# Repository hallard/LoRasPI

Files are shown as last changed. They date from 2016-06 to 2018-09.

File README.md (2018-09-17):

Raspberry PI Lora Gateway/Node for RFM92/95/96/98/69HCW Modules
===============================================================

This shield is used to hold HopeRF [Lora module][4] Software with Raspbery PI. it has just few minimal features and it's working for [TTN network][1]. 

I tweaked the [Single LoraWan Gateway][5] to get it working out of the box. It should also works with [HAB Supplies Lora Gateway][7] (same pinout), see this excellent [Dave's article][6].

This shield can also act as a LoraWAN Node/gateway using this custom dedicated software    
- RPI version of [LMIC][9] stack. This LMIC is working with this shield, see [readme][13] of repo.
- for RF69 networks using the excellent [RadioHead][10] customized library. This version is working with this shield, see [readme][12] of library.

As you can see, this shield is small but can do a lot but if you need a shield with more features (modules) on same board, I've designed a more featured one. It's called RPI Lora Gateway, you can go [here][11] to see it.

Features
========
- Placement for RFM92/95/96/98 Lora module or RFM69HCW classic module
- Placement for choosing single Wire, SMA or u-FL Antenna type
- 2 x LED LED for visual indication

**New in Version 1.2a**

- V1.2 CS trace missing fixed

**New in Version 1.2**

- R3 Error corrected, it's now a Pull Down
- DIO5 connection to GPIO24 removed, not used
- 2nd led is now connected to GPIO24 instead of CS line

**Error in V1.2, one small trace on CS (CE0 and CE1) signal is missing, fixed in V1.2a**, I really apologize for this error, Eagle beginner error, ALWAYS place junction on schematic, because sometime it looks like connected but it's not!

Here is how to fix this V1.2 trace missing

Clean Way (experienced soldering user)
---------------------------------------
With a small cutter or tool remove silk to bring via copper visible, then solder a tiny wire from CS pad to Via as follow (in green)
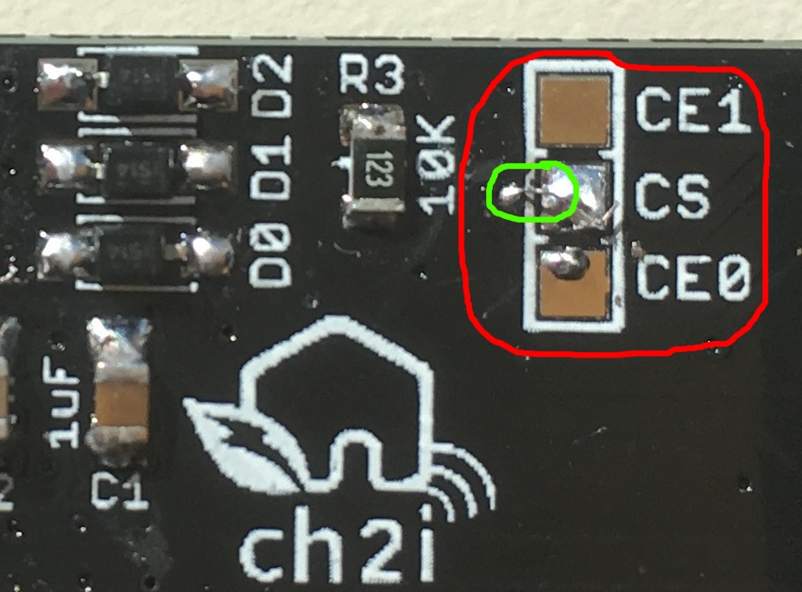
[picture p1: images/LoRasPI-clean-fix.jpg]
LoRasPI V1.2 Clean trace fix


Easy Way
--------
Just route the CE0 or CE1 signal with a small wire dirctly to RFM9x module as follow
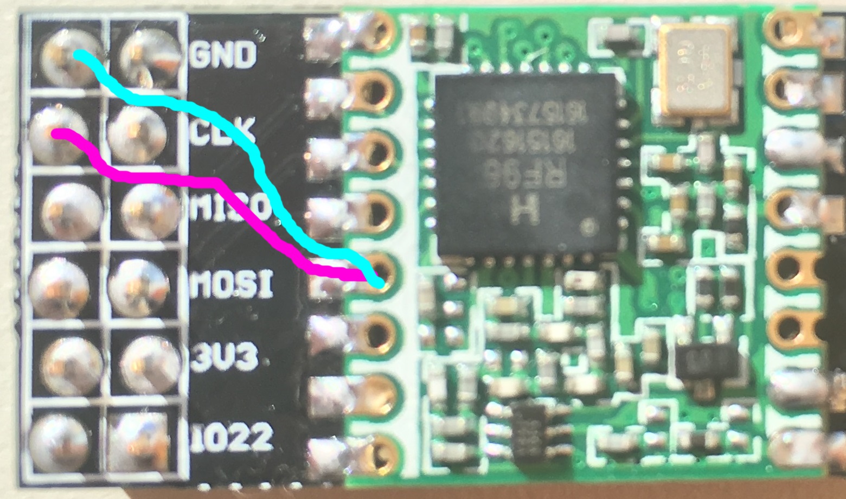
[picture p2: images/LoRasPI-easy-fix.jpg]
LoRasPI V1.2 Easy trace fix

Use purple wire if you want to use CE0 and Cyan for CE1

**New in Version 1.1**

- Reduced board width so it can be soldered on 2x40 pins connector to expose other GPIOs
- Added DIO1 and DIO2 OR'ed with DIO0 and 1N4148 diode to conform LIMC stack
- Better ground plane isolation
- Added some via on RF part 

I'm waiting now new V1.1 and V1.2 boards from OSHPark and PCBs.io, so I didn't fully tested V1.1/V1.2 yet, I will update ASAP.

I discovered a design error on V1.1, R3 resistor should be a pull down resistor and not a pull up, so **you should not populate R3, do not place it**, it's not a real problem since software will activate pull down of the BCM2835 controller but it's corrected in V1.2

~~I'm waiting boards V1.0~~ Boards arrived from OSHPark, all is working as expected (V1.0). ~~so I didn't fully tested them yet, I will update ASAP~~.

Detailed Description
====================

Look at the schematics for more informations.

SPI connexion is classic (MOSI/MISO/CLK), Chip Select can be connected to CE0 or CE1 of PI depending on bord solder PAD jumper.
Take care that by default it's connected to CE0 (wired) so you don't have to do anything. If you want to connect to CE1 you'll need to cut CE0 trace on the PCB (on the solder pad).

Only One GPIO needed for DIO0/DIO1/DIO2 (OR made with 3 diodes and one resistor R3) that will make this board fully compatible with current LIMC implementation, even if I've done a software fix which works with no interrupt. Only Needed for Lora modules, if you're using RFM69HCW and and to use IRQ just place D0 and R3.

~~Other pins that may need be adapted into code (for example if you use TTN network gateway code) according to the following pinout~~ This [Single LoraWan Gateway][5] has been tweaked and works right out of the box.

Detailed Description
====================

**Since V1.2**
```
Raspberry PI   RFM9x Module 1
   GPIO22  <---->  Reset
   GPIO25  <---->  DIO0 OR DIO1 OR DIO2 (Hardware OR done with 1N4148 Diode and R3)

Raspberry PI   On Board LEDS
   GPIO23  <---->  LED D3 TX/RX
   GPIO24  <---->  LED D4 LED
```

**V1.0 and V1.1**
```
Raspberry PI   RFM9x Module 1
   GPIO22  <---->  Reset
   GPIO25  <---->  DIO0 OR DIO1 OR DIO2 (Hardware OR done with 1N4148 Diode and R3)
   GPIO24  <---->  DIO5 (Ready)

Raspberry PI   On Board LEDS
   GPIO23  <---->  LED D1 TX/RX
CE0 or CE1 <---->  LED D2 CS
```

### Schematic  
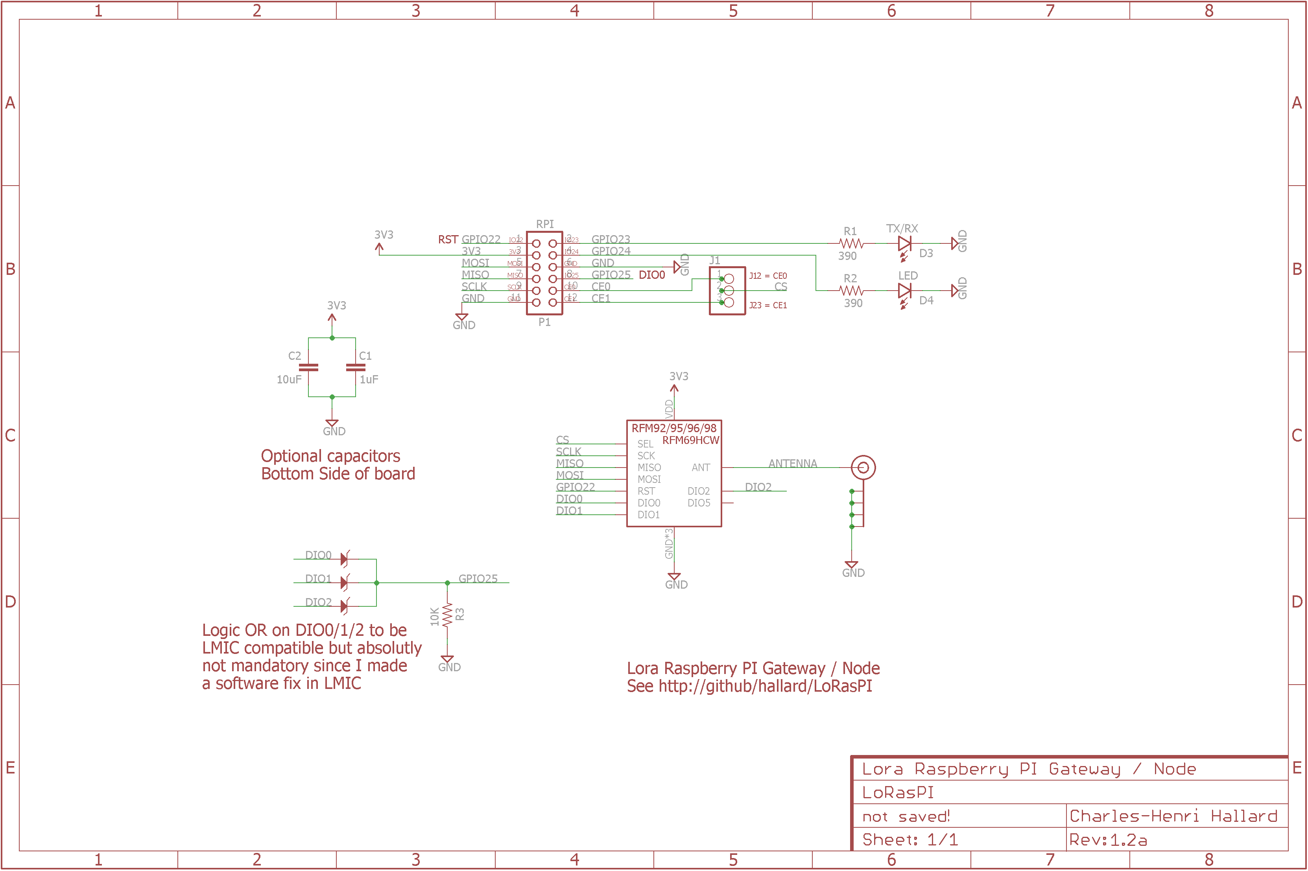
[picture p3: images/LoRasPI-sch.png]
schematic
  

### Boards  
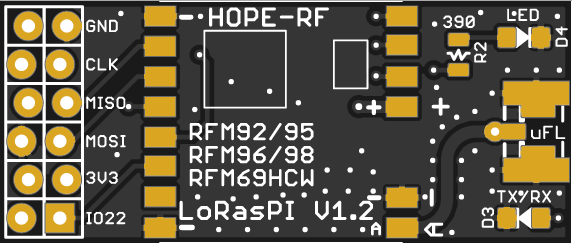
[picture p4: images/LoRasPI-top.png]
Top
    

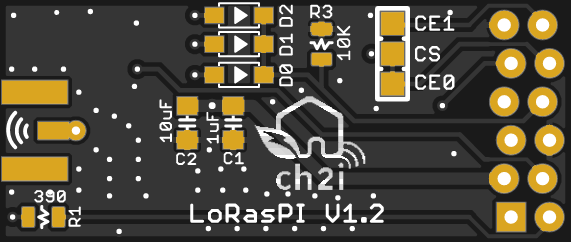
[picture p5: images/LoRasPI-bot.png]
Bottom
 

### Assembled boards (V1.0)

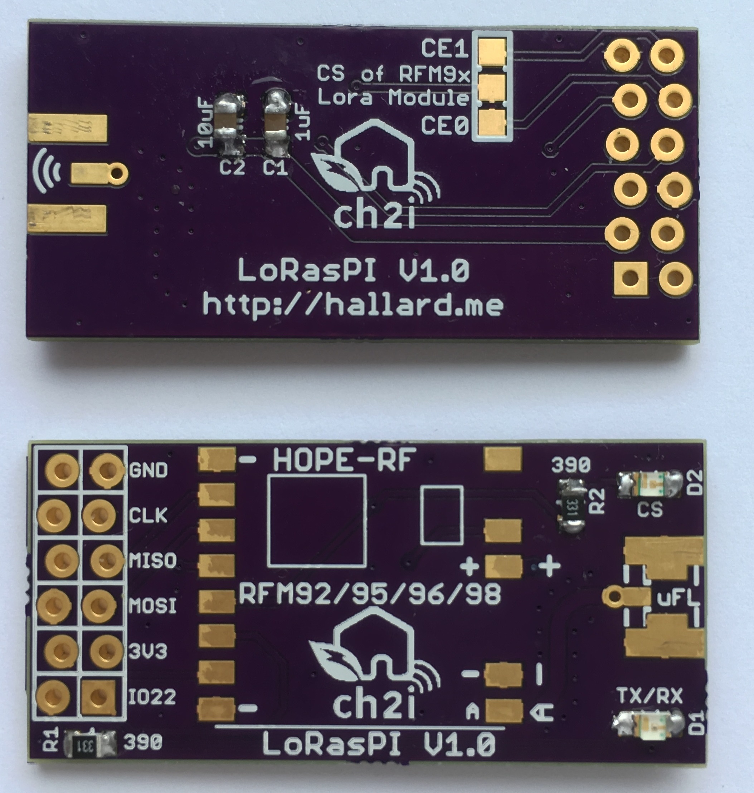
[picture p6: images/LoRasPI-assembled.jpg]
Assembled
    

V1.0 connected to Raspberry PI.

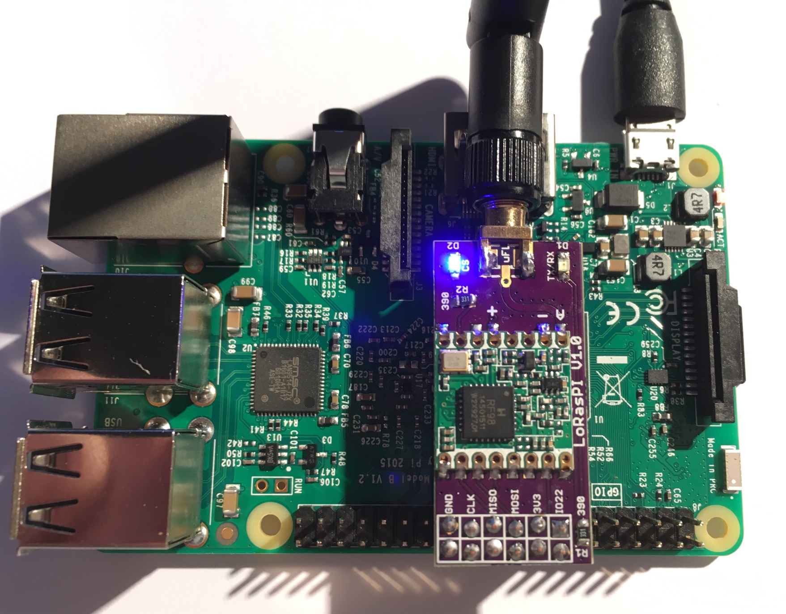
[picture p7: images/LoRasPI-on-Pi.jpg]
LoRasPI plugged on PI


You can order the PCB of this board at [OSHPARK][3] (V1.1) or new V1.2a at [PCBs.io][8]. PCBs.io give me some reward when you order my designed boards from their site. This is pretty good, because I can use these rewards to create and design new boards and order boards for a discounted price and share new boards. So if you don't care about PCB manufacturer please use PCBs.io.

##License

You can do whatever you like with this design.

##Misc

See news and other projects on my [blog][2] 

[1]: https://staging.thethingsnetwork.org/wiki/Hardware/Gateways/DIY 
[2]: https://hallard.me
[3]: https://oshpark.com/shared_projects/BVwV2j3b
[4]: http://www.hoperf.com/rf_transceiver/lora/
[5]: https://github.com/hallard/single_chan_pkt_fwd
[6]: http://www.daveakerman.com/?p=1719
[7]: https://store.uputronics.com/index.php?route=product/product&search=lora&product_id=68
[8]: https://PCBs.io/share/4q9kM
[9]: https://github.com/hallard/arduino-lmic/tree/rpi
[10]: https://github.com/hallard/RadioHead
[11]: https://github.com/hallard/RPI-Lora-Gateway
[12]: https://github.com/hallard/RadioHead/blob/master/README.md
[13]: https://github.com/hallard/arduino-lmic/blob/rpi/README.md

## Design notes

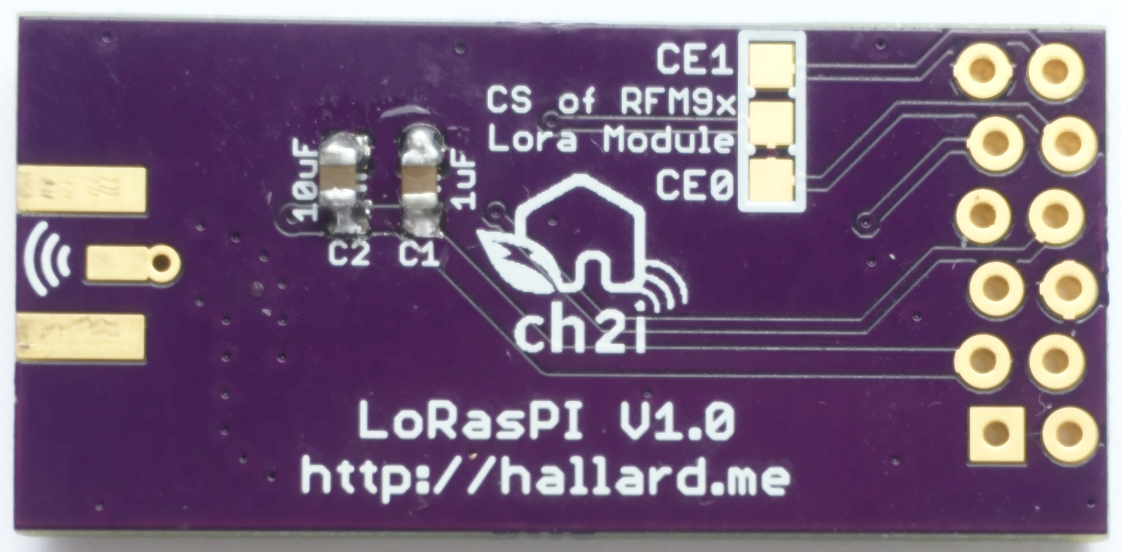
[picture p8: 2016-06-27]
images/LoRasPI-bot.jpg

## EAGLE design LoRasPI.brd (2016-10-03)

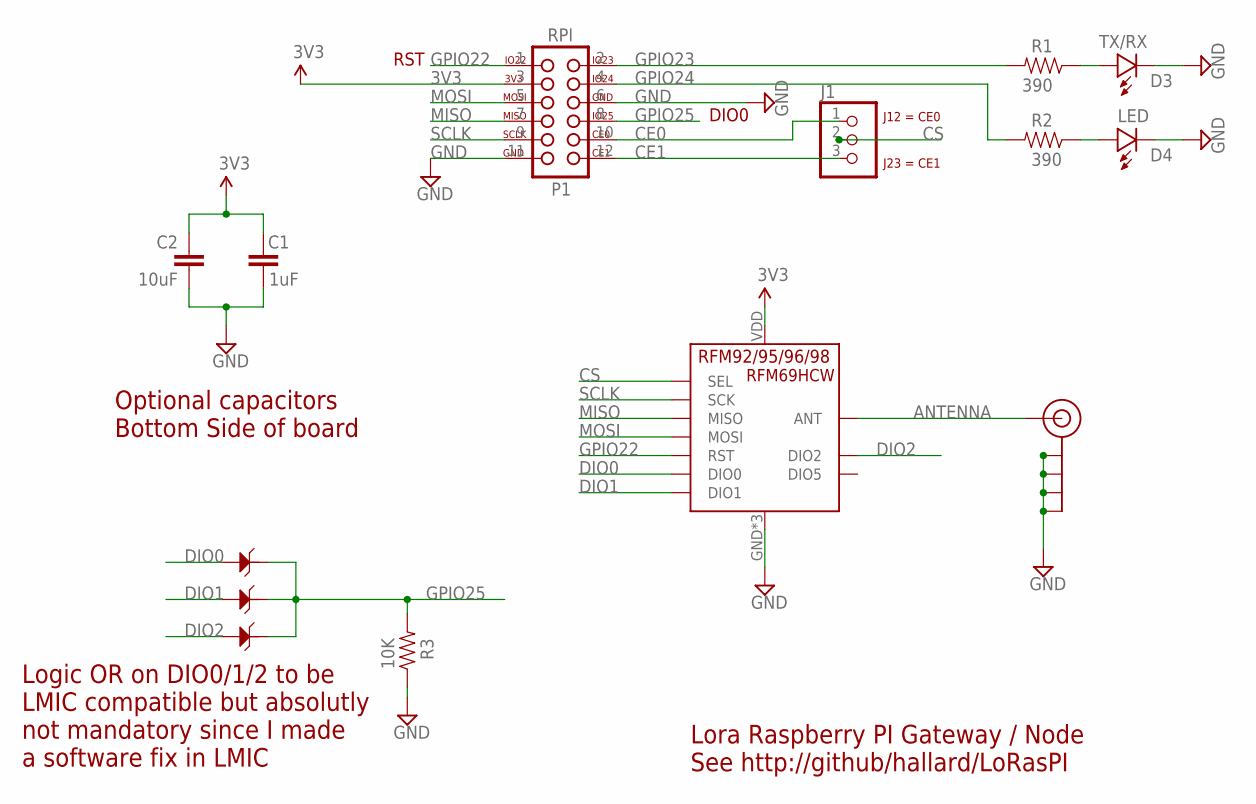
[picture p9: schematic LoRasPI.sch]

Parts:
C1: 1uF; 0805-CAP-LARGEPADS
C2: 10uF; 0805-CAP-LARGEPADS
D0, D1, D2: 1N4148; SOD123-2.7X1.6
D3: TX/RX; 0805-LED-LARGEPADS
D4: LED; 0805-LED-LARGEPADS
HOPE-RF: RFM92/95/96/98; RFM95
J1: JUMPER_1X30805; JP3_0805
J$1: ANTENNATINY; SMA_UFL_PAD_TINY
R1, R2: 390; 0805-RES
R3: 10K; 0805-RES
U$2: RASPBERRY_PI_2X6_BOTTOM; 2X06_LOCK

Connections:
3V3: C1.2, C2.2, HOPE-RF.VDD (VCC), U$2.3 (17)
ANTENNA: HOPE-RF.ANT, J$1.ANT1 (SIGNAL), J$1.ANT2 (SIGNAL), J$1.ANT3 (SIGNAL)
CE0: J1.1, U$2.10 (24)
CE1: J1.3, U$2.12 (26)
CS: HOPE-RF.NSS (SEL), J1.2
DIO0: D0.1, HOPE-RF.DIO0
DIO1: D1.1, HOPE-RF.DIO1
DIO2: D2.1, HOPE-RF.DIO2
GND: C1.1, C2.1, D3.MINUS, D4.MINUS, HOPE-RF.GND, HOPE-RF.GND1 (GND), HOPE-RF.GND2 (GND), J$1.GND1 (GND), J$1.GND2 (GND), J$1.GND3 (GND), J$1.GND4 (GND), R3.1, U$2.6 (20), U$2.11 (25)
GPIO22: HOPE-RF.RST, U$2.1 (15)
GPIO23: R1.2, U$2.2 (16)
GPIO24: R2.2, U$2.4 (18)
GPIO25: D0.2, D1.2, D2.2, R3.2, U$2.8 (22)
MISO: HOPE-RF.MISO, U$2.7 (21)
MOSI: HOPE-RF.MOSI, U$2.5 (19)
unnamed: D3.PLUS, R1.1
unnamed: D4.PLUS, R2.1
SCLK: HOPE-RF.SCK, U$2.9 (23)

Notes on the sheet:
Lora Raspberry PI Gateway / Node
See http://github/hallard/LoRasPI
Optional capacitors Bottom Side of board
RFM69HCW
Logic OR on DIO0/1/2 to be LMIC compatible but absolutly not mandatory since I made a software fix in LMIC
RST
DIO0

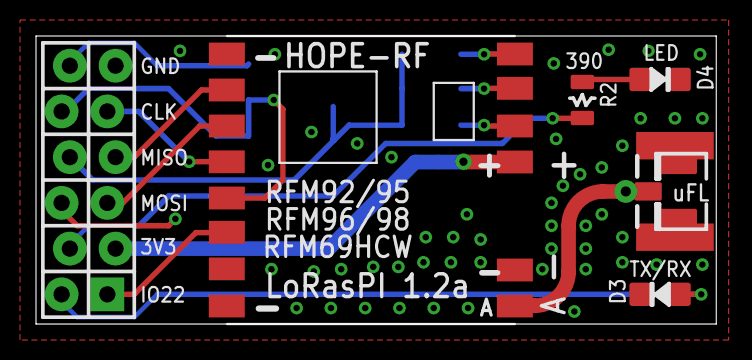
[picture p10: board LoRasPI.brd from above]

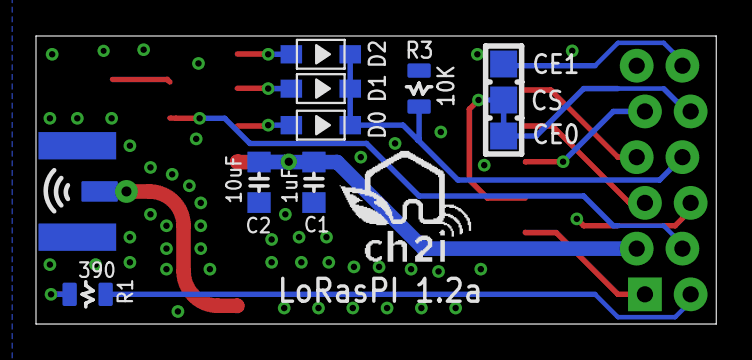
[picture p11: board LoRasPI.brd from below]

Board: 2 copper layers, 37.8 x 16.0 mm, 15 parts (9 on the bottom side), 18 nets.

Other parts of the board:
U$4: LOGO_CH2I_75MM

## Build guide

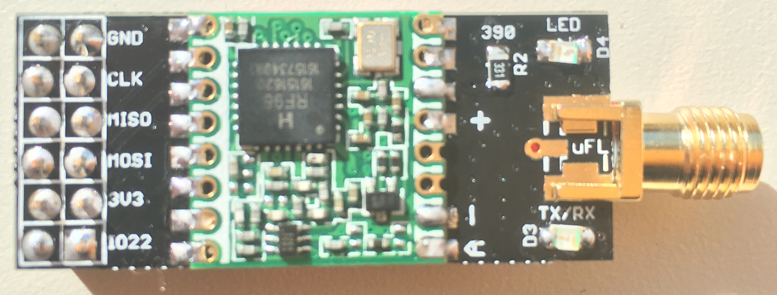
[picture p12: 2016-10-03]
images/LoRasPI-top-assembled.jpg

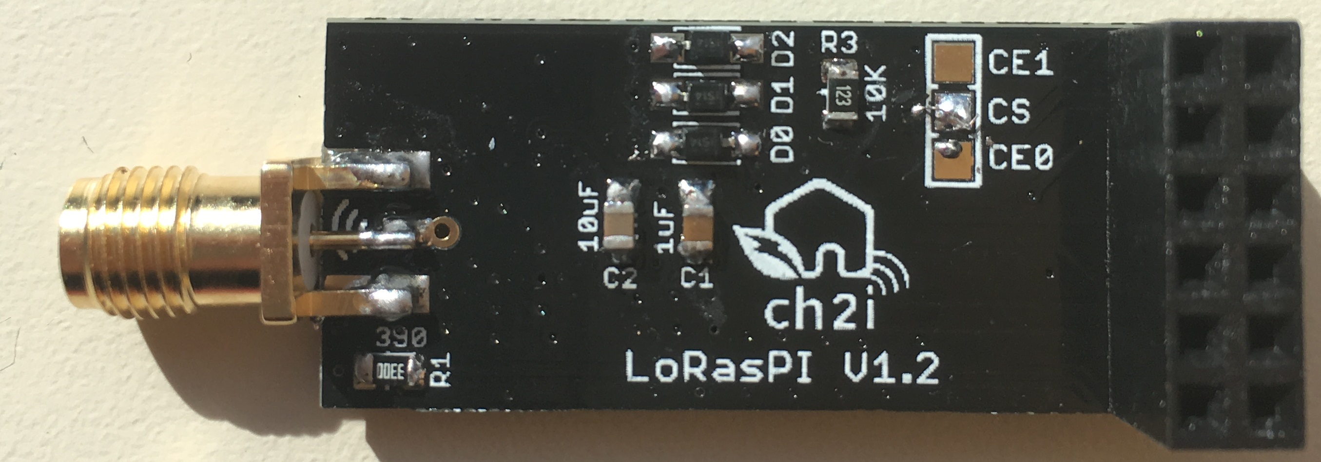
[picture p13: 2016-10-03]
images/LoRasPI-bot-assembled.jpg

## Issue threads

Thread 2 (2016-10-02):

problem

alex1sh, 2016-10-02:
Hi,

Did you test v1.2 please? I have two boards (one with rfm95w and another one with rfm68hcw) and both of them have problems. Transceivers are not detected by spi_scan., On both I connected D0 with 1N4148 and have R3 in place. Anything in particular I should check?

My RPi3 is detecting other boards with rfm95w with no problem.

Thanks
Alex

hallard, 2016-10-03:
@alex1sh
Since V1.0 and V1.1 are working fine and I didn't make so much change between then it's very strange.
I have boards but not assembled/tested them yet, I need to check.

You're wiring is correct, did you enabled SPI kernel module on RPI?
Does the reset line of the module (GPIO22) is in the correct state ? should be low for RFM69HCW and high for RFM95 ?

hallard, 2016-10-03:
I took some time to assemble one during lunch time,you're right there is one error on V1.2, a small missing trace on CS signal prevent board from working, I updated to V1.2a and provided a fix for V1.2, you can see [ReadMe](https://github.com/hallard/LoRasPI/blob/master/README.md) for how to fix this error.

I really apologize for this!

alex1sh, 2016-10-03:
@hallard

Thanks Charles. I have corrected my version (hard fix) and tested it with the multimeter and I can see that CE rfm95w pin is now connected to GPIO07 (pin #26) on P1. However, I am still struggling to make it work:

pi@m:~/RadioHead/examples/raspi/spi_scan $ sudo ./spi_scan
Checking register(0x42) with CS=GPIO06 => Nothing!
Checking register(0x10) with CS=GPIO06 => Nothing!
Checking register(0x42) with CS=GPIO08 => Nothing!
Checking register(0x10) with CS=GPIO08 => Nothing!
Checking register(0x42) with CS=GPIO07 => Nothing!
Checking register(0x10) with CS=GPIO07 => Nothing!
Checking register(0x42) with CS=GPIO26 => Nothing!
Checking register(0x10) with CS=GPIO26 => Nothing!
pi@m:~/RadioHead/examples/raspi/spi_scan $ sudo ./spi_scan
Checking register(0x42) with CS=GPIO06 => Unknown (V=0x40)
Checking register(0x10) with CS=GPIO06 => Unknown (V=0x40)
Checking register(0x42) with CS=GPIO08 => Unknown (V=0x40)
Checking register(0x10) with CS=GPIO08 => Unknown (V=0x40)
Checking register(0x42) with CS=GPIO07 => Unknown (V=0x40)
Checking register(0x10) with CS=GPIO07 => Unknown (V=0x40)
Checking register(0x42) with CS=GPIO26 => Unknown (V=0x40)
Checking register(0x10) with CS=GPIO26 => Unknown (V=0x40)

I have only D0 in place so maybe this is a problem?

hallard, 2016-10-04:
Alex,
I can't test it right now, but spi_scan from my radioHead library may be different than the one from LMIC version I tested LoRasPI with. Would you please check with this LMIC RPI version just to be sure?
https://github.com/hallard/arduino-lmic/tree/rpi
spi_scan is under `examples/raspi/`
https://github.com/hallard/arduino-lmic/tree/rpi/examples/raspi/spi_scan

alex1sh, 2016-10-05:
No, the other spi_scan is giving me the same result. No luck.
The Single Channel LoRaWAN Gateway is not working either. I can see the LED flashing a few times and that's it when I execute the command:

pi@m:~/single_chan_pkt_fwd $ sudo ./single*
server: .address = router.eu.staging.thethings.network; .port = 1700; .enable = 1
server: .address = router.eu.thethings.network; .port = 1700; .enable = 0
Gateway Configuration
  SC Gateway (contact@whatever.com)
  Dragino Single Channel Gateway on RPI
  Latitude=0.00000000
  Longitude=0.00000000
  Altitude=10
Trying to detect module with NSS=10 DIO0=6 Reset=3 Led1=4
Transceiver version 0x00
Unrecognized transceiver: Connection timed out

I'll try to solder other diodes and see if it makes any difference.

hallard, 2016-10-05:
Oh sorry, diode will not change anything they are used for IRQ once device is running.
Are you using latest raspian on your RPI?

hallard, 2016-10-05:
May be checking SPI line connection like you done for CS line, I don't see why it does not works? IT works on mine

alex1sh, 2016-10-06:
OK, I must admit that I forgot to stop domoticz service, which was trying to use SPI to detect nrf24l01+.
This has caused the problem.

Trying now to detect the module, but it does not work 100%

pi@m:~/arduino-lmic/examples/raspi/spi_scan $ sudo ./spi*
Checking register(0x42) with CS=GPIO24 => Nothing!
Checking register(0x10) with CS=GPIO24 => Nothing!
Checking register(0x42) with CS=GPIO08 => Nothing!
Checking register(0x10) with CS=GPIO08 => Nothing!
Checking register(0x42) with CS=GPIO07 => Nothing!
Checking register(0x10) with CS=GPIO07 => Nothing!
Checking register(0x42) with CS=GPIO26 => Nothing!
Checking register(0x10) with CS=GPIO26 => Nothing!
pi@m:~/arduino-lmic/examples/raspi/spi_scan $ sudo ./spi*
Checking register(0x42) with CS=GPIO24 => Nothing!
Checking register(0x10) with CS=GPIO24 => Nothing!
Checking register(0x42) with CS=GPIO08 => SX1276 RF95/96 (V=0x12)
Checking register(0x10) with CS=GPIO08 => Nothing!
Checking register(0x42) with CS=GPIO07 => Nothing!
Checking register(0x10) with CS=GPIO07 => Nothing!
Checking register(0x42) with CS=GPIO26 => Nothing!
Checking register(0x10) with CS=GPIO26 => Nothing!

Anyway, the Single LoraWan Gateway is working and that's the key. Thanks for your help.

alex1sh, 2016-10-06:
But the way the LED only comes on after I do spi_scan. Is it supposed to be like that?
(The other one comes on when transmitting/receiving, right?)

alex1sh, 2016-10-13:
Thank you for your help and sharing your knowledge - very much appreciate it.

Unfortunately, the board does not work in my case.. I tried to install a new Jessie (Sep 2016) and still I have the following:

Message from syslogd@rpi3 at Oct 13 09:33:10 ...
 kernel:[32568.765124] Disabling IRQ #79

I cannot receive messages. I tried several boards with rfm69hcw and rfm95w with the same result. Single Channel GW does not seem to work as I cannot connect a node (Sodaq ONE) to it. It does update the GW status here though:
https://www.thethingsnetwork.org/api/v0/gateways/B827EBFFFF0247FA/

but no reception from nodes.
Perhaps I am doing something very silly...

hallard, 2016-10-13:
@alex1sh
I'm using the 3 version of Loraspi (V1.0, V1.1 and V1.2) on 3 different RPI without any problem.

What software are you running with LoRasPI board and what the log are saying ?

PS : I've updated spi_scan to avoid detection problem at 1st launch, now it set up all CS possible line to High before doing a scan

alex1sh, 2016-10-14:
Clearly, I am doing something wrong. The problem is that I just cannot link the node and the GW.
Running your modified GW gives me this:

pi@rpi3:~/old/single_chan_pkt_fwd $ sudo ./single*
server: .address = router.eu.staging.thethings.network; .port = 1700; .enable = 0
server: .address = router.eu.thethings.network; .port = 1700; .enable = 1
Gateway Configuration
  SC Gateway (contact@whatever.com)
  Single Channel Gateway on RPI
  Latitude=51.47623062
  Longitude=-0.12268900
  Altitude=7
Trying to detect module with NSS=10 DIO0=6 Reset=3 Led1=4
SX1276 detected, starting.
Gateway ID: b8:27:eb:ff:ff:02:47:fa
Listening at SF7 on 868.100000 Mhz.
-----------------------------------
stat update: 2016-10-14 00:47:52 GMT no packet received yet
stat update: 2016-10-14 00:48:22 GMT no packet received yet
stat update: 2016-10-14 00:48:52 GMT no packet received yet
stat update: 2016-10-14 00:49:22 GMT no packet received yet
stat update: 2016-10-14 00:49:52 GMT no packet received yet
stat update: 2016-10-14 00:50:22 GMT no packet received yet
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
alex1sh, 2016-10-14:
To eliminate the issue of SX1276, trying otaa on the RPi3:

pi@rpi3:~/arduino-lmic/examples/raspi/ttn-otaa $ sudo ./ttn-otaa
ttn-otaa Starting
RFM95 device configuration
CS=GPIO8 RST=GPIO22 LED=GPIO23 DIO0=Unused DIO1=Unused DIO2=Unused
DevEUI : B8*****************
AppEUI : 70B3D5***********
AppKey : F8*****************************
RXMODE_RSSI
10:38:06: 542: engineUpdate, opmode=0x8
Packet queued
10:38:06: EV_JOINING
547: engineUpdate, opmode=0xc
274197: engineUpdate, opmode=0xc
274260: TXMODE, freq=868500000, len=23, SF=7, BW=125, CR=4/5, IH=0
590778: RXMODE_SINGLE, freq=868500000, SF=7, BW=125, CR=4/5, IH=0
656254: RXMODE_SINGLE, freq=869525000, SF=12, BW=125, CR=4/5, IH=0
666669: engineUpdate, opmode=0xc
4451325: engineUpdate, opmode=0xc
4451382: TXMODE, freq=868100000, len=23, SF=7, BW=125, CR=4/5, IH=0
4767899: RXMODE_SINGLE, freq=868100000, SF=7, BW=125, CR=4/5, IH=0
4833375: RXMODE_SINGLE, freq=869525000, SF=12, BW=125, CR=4/5, IH=0
4843795: engineUpdate, opmode=0xc
9082304: engineUpdate, opmode=0xc
9082362: TXMODE, freq=868300000, len=23, SF=8, BW=125, CR=4/5, IH=0
9402151: RXMODE_SINGLE, freq=868300000, SF=8, BW=125, CR=4/5, IH=0
9467531: RXMODE_SINGLE, freq=869525000, SF=12, BW=125, CR=4/5, IH=0
9477947: engineUpdate, opmode=0xc
17246128: engineUpdate, opmode=0xc
17246186: TXMODE, freq=868500000, len=23, SF=8, BW=125, CR=4/5, IH=0
17565975: RXMODE_SINGLE, freq=868500000, SF=8, BW=125, CR=4/5, IH=0
17631355: RXMODE_SINGLE, freq=869525000, SF=12, BW=125, CR=4/5, IH=0
17641771: engineUpdate, opmode=0xc
24686286: engineUpdate, opmode=0xc
24686346: TXMODE, freq=868100000, len=23, SF=9, BW=125, CR=4/5, IH=0
25012136: RXMODE_SINGLE, freq=868100000, SF=9, BW=125, CR=4/5, IH=0
25077324: RXMODE_SINGLE, freq=869525000, SF=12, BW=125, CR=4/5, IH=0
25087743: engineUpdate, opmode=0xc
38116791: engineUpdate, opmode=0xc
38116846: TXMODE, freq=868300000, len=23, SF=9, BW=125, CR=4/5, IH=0
38442641: RXMODE_SINGLE, freq=868300000, SF=9, BW=125, CR=4/5, IH=0
38507830: RXMODE_SINGLE, freq=869525000, SF=12, BW=125, CR=4/5, IH=0
38518252: engineUpdate, opmode=0xc

and it never JOINED.
The keys are correct, I had them checked many times (DevEUI and AppEUI had to be in endian format and AppKey is in the normal format). No wonder that ttnctl is telling me:

ttnctl.exe devices info B827EB5712AF0400
Dynamic device:

  AppEUI:  70B3D57ED0001135
           {0x70, 0xB3, 0xD5, 0x7E, 0x--, 0x--, 0x--, 0x--}

  DevEUI:  B827EB5712AF0400
           {0xB8, 0x27, 0x--, 0x--, 0x--, 0x--, 0x--, 0x--}

  AppKey:  F87BA0E8972E044CA51235C8E2757008
           {0xF8, 0x--, 0x--, 0x--, 0x--, 0x--, 0x--, 0x--, 0x--, 0x--, 0x--, 0x--, 0x--, 0x--, 0x--, 0x--}

  Not yet activated

alex1sh, 2016-10-14:
By the way thanks for fixing spi_scan - it works now!

hallard, 2016-10-14:
@alex1sh
you're using a full lorawan device (RN2483) with a degraded version (single channel gateway) which is not full lorawan compliant. I'm not a specialist but I think this is why it's not working
May be you'll have better answer on TTN forum for this issue.

alex1sh, 2016-10-15:
Thanks - you are right. This is a complex issue and I am waiting for an official TTN GW.  Unfortunately, TTN Forum is not very active - I did not get much reply over there.

I do not understand why ttn-otaa fails on my RPi.  RPi is sending the request directly to TTN server or is looking for a GW?

hallard, 2016-10-17:
humm, I always find TTN very active, where is your topic ?

./ttn-otaa on RPI is looking for a gateway it's a client node

alex1sh, 2016-10-17:
https://www.thethingsnetwork.org/forum/t/sodaq-one-cannot-register-on-ttn/3734

OK, this explains why I cannot register with TTN running ./ottn-otaa.
Can I run both single channel packet forwarder and ./ttn-otaa on the same RPI?

hallard, 2017-08-15:
@alex1sh
you mean running both with 2 differents boards? If so, technically, yes but if you use two process you must ensure they do not talk SPI on the same time with semaphore or so. This need rewrite lot of code on both process, I can guarantee more pain than buying another RPI or a WeMos with RFM95 for ttn otaa ;-)

Closed 2017-08-15.

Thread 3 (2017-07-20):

Pin header specifications

StereotypicalSquirrel, 2017-07-20:
Do you have a part number for the pin header you are using? I'm having trouble finding a suitable header with staggered pins.

hallard, 2017-08-15:
I'm using classic 2x6 pins header without any problem
search on ebay for
```
2X6 pins 2.54
```
like this [one](http://www.ebay.com/itm/181846910842)

Closed 2017-08-15.

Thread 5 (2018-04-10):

Pin Mapping

MichaelSmi, 2018-04-10:
Hi Charles,

first thank you very much for creating and sharing your PCB here!

I'd like to use your board (I ordered 8) like a breakout board.
I cant figure out the pin mapping on the left pin column of the LoRasPi 1.2a.
I'd like to connect those pins to an Arduino pro mini.

I made the following pin mapping:

 LoRasPI | RFM65 | Arduino Pro Mini
------------ | ------------- | -------------
 GND | GND | GND
 MISO | MISO | MISO
 MOSI | MOSI | MOSI
 3V3 | VCC | VCC
 IO22 | RST | RST
 D0 | DIO 0 | D4
 D1 | DIO 1 | D5
 D2 | DIO 2 | D7
 CE0 | ? | ?
 CS | ? | ?
 CE1 | ? | ?

Is the map correct? Could you please correct any errors on LoRasPI col?

hallard, 2018-09-17:
You're Arduino don't have CE0/CE1 choice, so you just need to connect CS to SS pin (D10 ?)

Closed 2018-09-17.

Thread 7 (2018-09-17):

OR gate for DIOx

mrubioroy, 2018-09-17:
On the schematics you show three Zener diodes for the OR logic gate between DIO0, DIO1 and DIO2. Must they be Zener or any other type should do? What are the characteristics needed for those diodes? I'm guessing they should be 3216 size from the PCB dimensions.

Thanks

hallard, 2018-09-17:
Yeah schematic symbol may not be accurate and should not be Zener diode.
Diode are 1N4148 or Schottky in SOD123 package.

Closed 2018-09-17.

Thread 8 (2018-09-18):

Antenna PCB trace

gmsotavio, 2018-09-18:
Hi Dear,

I noticed that there are a split in the board ground plane bellow antenna PCB trace, near of ANT pin of the RF module. Is this OK ? Just another question. Has the antenna PCB trace, 50 ohm impedance ?

Regards

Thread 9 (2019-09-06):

Lots of packets

jorgebnunes, 2019-09-06:
Hi Charles,

first of all, great work!

I've managed to construct this gateway and used your version of single packet forwarder, but I'm getting these continuous messages:

Packet RSSI: -157, RSSI: -103, SNR: 0, Length: 0 Message:''
rxpk update: {"rxpk":[{"tmst":2479877867,"freq":868.1,"chan":0,"rfch":0,"stat":1,"modu":"LORA","datr":"SF7BW125","codr":"4/5","rssi":-157,"lsnr":0.0,"size":0,"data":""}]}
Packet RSSI: -157, RSSI: -106, SNR: 0, Length: 0 Message:''
rxpk update: {"rxpk":[{"tmst":2479887927,"freq":868.1,"chan":0,"rfch":0,"stat":1,"modu":"LORA","datr":"SF7BW125","codr":"4/5","rssi":-157,"lsnr":0.0,"size":0,"data":""}]}
Packet RSSI: -157, RSSI: -104, SNR: 0, Length: 0 Message:''
rxpk update: {"rxpk":[{"tmst":2479898742,"freq":868.1,"chan":0,"rfch":0,"stat":1,"modu":"LORA","datr":"SF7BW125","codr":"4/5","rssi":-157,"lsnr":0.0,"size":0,"data":""}]}
Packet RSSI: -157, RSSI: -104, SNR: 0, Length: 0 Message:''
rxpk update: {"rxpk":[{"tmst":2479908300,"freq":868.1,"chan":0,"rfch":0,"stat":1,"modu":"LORA","datr":"SF7BW125","codr":"4/5","rssi":-157,"lsnr":0.0,"size":0,"data":""}]}

On the hardware I soldered the three DIO diodes and I think the rest is OK.

my config is:

pi@raspberrypi:~/single_chan_pkt_fwd $ sudo ./single_chan_pkt_fwd
server: .address = router.eu.staging.thethings.network; .port = 1700; .enable = 1
server: .address = router.eu.thethings.network; .port = 1700; .enable = 0
Gateway Configuration
  JN GW (jorg...@gmail.com)
  Dragino Single Channel Gateway on RPI
  Latitude=0.00000000
  Longitude=0.00000000
  Altitude=10
Trying to detect module with NSS=8 DIO0=6 Reset=3 Led1=5
SX1276 detected, starting.
Gateway ID: b8:27:eb:ff:ff:63:c8:99
Listening at SF7 on 868.100000 Mhz.
-----------------------------------
stat update: 2019-09-06 12:28:26 GMT no packet received yet
Packet RSSI: -157, RSSI: -105, SNR: 0, Length: 0 Message:''

Can you help?

Thanks a lot!

Jorge

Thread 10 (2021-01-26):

leds not working

geologic, 2021-01-26:
Hi

I just build a LorasPI PCB V1.2a and installed Single Channel LoRaWAN Gateway on a Raspberry Pi 4. I think gateway is running ok, terminal shows

```
Trying to detect module with NSS=8 DIO0=6 Reset=3 Led1=4
SX1276 detected, starting.
Gateway ID: dc:b6:32:ff:fa:4c:a5:a3
Listening at SF7 on 868.100000 Mhz.
-----------------------------------
stat update: 2021-01-26 12:35:03 GMT no packet received yet
stat update: 2021-01-26 12:35:33 GMT no packet received yet

```

and i can see it online on TTN dashboard.

The problem is none of the leds light up, at least LED shouldn't be on?
I already checked led polarity or any missing solder/bad components.

Any idea?

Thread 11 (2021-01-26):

CS pin clarification

geologic, 2021-01-26:
I'm using a LoRasPI PCB V1.2a with Single Channel LoRaWAN Gateway installed on a Raspberry Pi 4.
According to your schematic, NSS pin from lora module is connected to CE0 pin on the raspberry, so pin 10 on Wiring Pi.

On global_conf.json, you have for LoRasPi: "pin_nss": 8,
shouldn't be "pin_nss": 10?

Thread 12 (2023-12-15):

Seeking Guidance on LoRa Project - Need Help with Forwarding Packets

hirdeshmewada, 2023-12-15:
Hello ,

I hope this message finds you well. My name is Hirdesh Mewada, and I'm currently working on a LoRa project that involves forwarding packets between LoRa modules. I'm reaching out to the community for guidance and assistance with a specific aspect of my project.

Project Overview:
I'm working on a system where LoRa Module 1 forwards packets. In this setup, when a user is connected to Module 2 (linked to an ESP32 board and acting as an access point), and they enter a URL like "google.com" on their smartphone, I aim to have the request travel from the user's device to the ESP32, then to LoRa Module 2, reaching LoRa Module 1. Module 1 is connected to a Raspberry Pi, which, in turn, is connected to the internet. The Raspi should forward the request to the internet, retrieve the response, and send it back to its connected LoRa Module 1. Finally, Module 1 should forward the response back to Module 2, which can then be accessed by the user on their smartphone. The primary goal is to enable users to view basic text-based HTML websites through this LoRa network.

Specific Assistance Needed:
I'm seeking guidance or examples of code related to the following aspects:

Configuring LoRa communication at 868MHz.
Handling specific LoRa settings for packet forwarding.
Implementing the communication flow from the user device to the Raspi and vice versa.
I understand that your expertise and insights would be invaluable, and I appreciate any guidance or examples you can provide. If there are specific resources, code snippets, or documentation within the LoRa community that could be relevant to my project, I would be grateful for your direction.

Additional Information:

I'm using the pyLoRa library for this project.
and raspi 3b+ ,esp32 ,2 rfm96 modules
Thank you for taking the time to read my query. I look forward to any assistance you can offer.

Best regards,
HIRDESH MEWADA
hirdeshrajput143@gmail.com

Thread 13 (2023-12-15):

Seeking Guidance on LoRa Packet Forwarding Project

hirdeshmewada, 2023-12-15:
Hello ,

I hope this message finds you well. My name is Hirdesh Mewada, and I'm currently working on a LoRa project that involves forwarding packets between LoRa modules. I'm reaching out to the community for guidance and assistance with a specific aspect of my project.

Project Overview:
I'm working on a system where LoRa Module 1 forwards packets. In this setup, when a user is connected to Module 2 (linked to an ESP32 board and acting as an access point), and they enter a URL like "google.com" on their smartphone, I aim to have the request travel from the user's device to the ESP32, then to LoRa Module 2, reaching LoRa Module 1. Module 1 is connected to a Raspberry Pi, which, in turn, is connected to the internet. The Raspi should forward the request to the internet, retrieve the response, and send it back to its connected LoRa Module 1. Finally, Module 1 should forward the response back to Module 2, which can then be accessed by the user on their smartphone. The primary goal is to enable users to view basic text-based HTML websites through this LoRa network.

Specific Assistance Needed:
I'm seeking guidance or examples of code related to the following aspects:

Configuring LoRa communication at 868MHz.
Handling specific LoRa settings for packet forwarding.
Implementing the communication flow from the user device to the Raspi and vice versa.
I understand that your expertise and insights would be invaluable, and I appreciate any guidance or examples you can provide. If there are specific resources, code snippets, or documentation within the LoRa community that could be relevant to my project, I would be grateful for your direction.

Additional Information:

I'm using the pyLoRa library for this project.
and raspi 3b+ ,esp32 ,2 rfm96 modules
Thank you for taking the time to read my query. I look forward to any assistance you can offer.

Best regards,
HIRDESH MEWADA
hirdeshrajput143@gmail.com

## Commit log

2016-06-03 Added warning on CE0/CE1 solder pad
2016-06-16 small typo in 'Optionnal'
    [LoRasPI.sch]
2016-06-27 Added pictures of assembled boards
2016-08-06 Bump to V1.1
    [LoRasPI.brd, LoRasPI.sch]
2016-08-22 Version 1.2
    [LoRasPI.brd, LoRasPI.sch]
2016-10-03 V1.2a, fixed missing trace
    [LoRasPI.brd, LoRasPI.sch]
2016-10-03 Added how to fi V1.2 missing trace
2016-10-03 V1.2 Assembled
2016-10-03 Updated PCBs.io link
2017-11-22 Update README.md
    labels of on board LEDs corrected

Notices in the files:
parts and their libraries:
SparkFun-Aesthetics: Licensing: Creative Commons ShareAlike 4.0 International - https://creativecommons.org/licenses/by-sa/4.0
